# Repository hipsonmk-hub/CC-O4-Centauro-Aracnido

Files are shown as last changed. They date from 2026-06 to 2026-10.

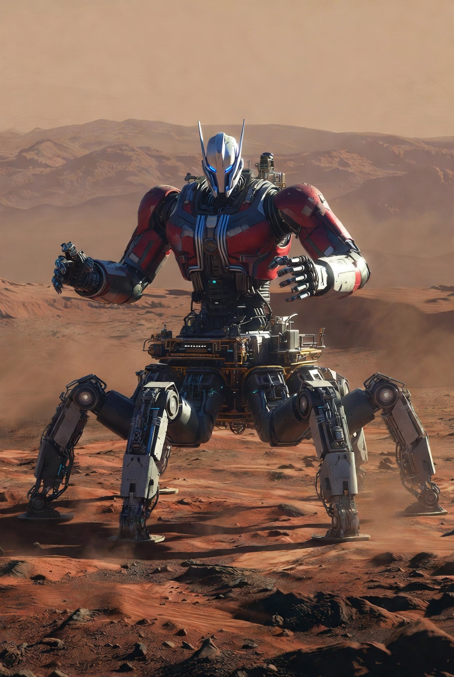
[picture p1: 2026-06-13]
image-1.jpg

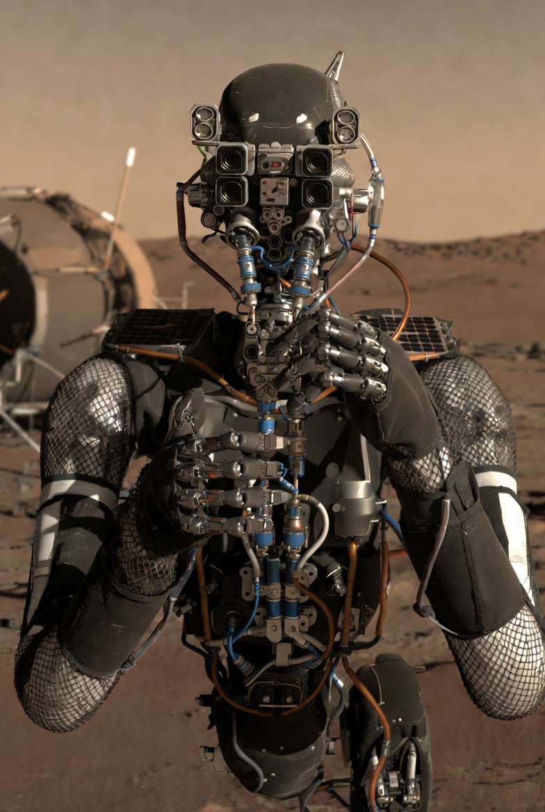
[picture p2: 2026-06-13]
image-3.jpg

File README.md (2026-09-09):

# CC-O4-Centauro-Aracnido
Arquitectura robótica híbrida Centauro-Arácnido para exploración lunar/marciana
# PROYECTO CC-04: ARQUITECTURA ROBÓTICA CENTAURO-ARÁCNIDO

**Solución Híbrida para Estabilidad y Operaciones Autónomas en Superficies Extraplanetarias**

**Código de Clasificación:** CC-O4-2026  
**Ecosistema Objetivo:** Exploración Lunar y Marciana (Compatibilidad Starship)  
**Fecha de Emisión:** Junio de 2026  
**Desarrollador de Arquitectura:** David Dorado Blázquez Moraleda López

## 1. Resumen Ejecutivo

El presente documento define la arquitectura conceptual de la plataforma robótica híbrida **CC-O4 (Centauro-Arácnido)**, diseñada para superar las limitaciones de rovers de ruedas y bípedos en entornos de microgravedad y terreno irregular.

Integra:
- Base octópoda hiper-redundante para anclaje extremo
- Torso antropomórfico modular (compatible con Optimus)
- Ecosistema energético piezoeléctrico
- Refrigeración vascular por nanotubos
- Núcleo cognitivo Edge AI con protocolo de "Ancla Lógica"

## 2. Morfología Modular y Compatibilidad "Plug & Play"

- **Base Octópoda de Anclaje Dinámico**: Ocho extremidades simétricas radiales. Centro de gravedad ultra-bajo y tolerancia a fallos (redistribución automática de carga).
- **Torso Humanoide Superior (Modularidad Optimus)**: Plataforma desmontable que permite acoplar directamente un torso humanoide estándar, combinando movilidad todoterreno con destreza fina.

## 3. Subsistemas Termodinámicos y Materiales Avanzados

- **Sistema Vascular Termodinámico**: Refrigeración activa mediante bomba central y líquido iónico/galinstano circulando por capilares de nanotubos de carbono.
- **Blindaje**: Ópticas con Gorilla Glass aeroespacial y protección con mallas multicapa de Kevlar balístico.

## 4. Arquitectura Energética Descentralizada

- **Cosecha Piezoeléctrica Dinámica**: Transductores PVDF en articulaciones y almohadillas que convierten tensión mecánica en electricidad.
- **Carga Inalámbrica por Inducción**: Evita puertos físicos que se obstruirían con regolito.

## 5. Arquitectura Cognitiva de Borde (Edge AI)

- **Procesamiento Multimodal (Gemma 4)**: Coordinación perfecta entre las 8 patas y las manos.
- **Protocolo "Ancla Lógica" (🔱)**: En caso de sobrecarga de datos, suspende tareas secundarias y prioriza homeostasis térmica y fijación al terreno.

## 6. Roadmap y Protocolo de Pruebas Terrestres

- **Fase 1**: Simulación en análogo terrestre (Nodo Móstoles) – tracción asimétrica y cosecha piezoeléctrica.
- **Fase 2**: Simulación de sobrecarga cognitiva (estilo Tesla Dojo).
- **Fase 3**: Pruebas en cámara de vacío y despliegue lunar.

## 7. Matriz de Rendimiento Extraplanetario

| Morfología de Plataforma | Estabilidad Cinética | Motricidad Fina | Tolerancia a Fallos | Autosuficiencia | Adaptabilidad a Marte |
|---|---|---|---|---|---|
| Rover de Ruedas Estándar | Media | Nula/Limitada | Baja | Baja | Media |
| Bípedo Humanoide Puro | Baja (microgravedad) | Alta | Muy Baja | Media | Baja |
| **Centauro-Arácnido (CC-O4)** | **Excelente** | **Alta** | **Extrema** | **Alta** | **Alta** |

---

**Imágenes y visuales del concepto** (incluye las que adjuntaste):
- Robot centauro-arácnido en superficie marciana
- Instalación de paneles solares
- Detalles mecánicos y close-ups
- 
Copyright (c) 2026 David Dorado Blázquez Moraleda López (@Hipsonmk)

This source describes Open Hardware and is licensed under the CERN-OHL-S v2.

You may redistribute and modify this source and make products using it under the terms of the CERN-OHL-S v2 (https://ohwr.org/cern_ohl_s_v2.txt).
This source is distributed WITHOUT ANY EXPRESS OR IMPLIED WARRANTY, INCLUDING OF MERCHANTABILITY, SATISFACTORY QUALITY AND FITNESS FOR A PARTICULAR PURPOSE. Please see the CERN-OHL-S v2 for applicable conditions.

Source location: https://github.com/hipsonmk-hub/CC-O4-Centauro-Aracnido

As per CERN-OHL-S v2 section 4, should you produce hardware based on this source, you must maintain the Creator's attribution and provide access to the modifications under the same license.
## ⚙️ Arquitectura Paramétrica y Hardware Abierto

El núcleo mecánico de la plataforma CC-O4 está diseñado bajo un paradigma paramétrico en **OpenSCAD**, garantizando su replicabilidad y adaptabilidad para misiones terrestres (NEXUS SHELL) y aeroespaciales.

### Nodo de Articulación Principal (`cc_o4_joint_624zz.scad`)
El primer módulo liberado establece el estándar de tolerancia termomecánica para las extremidades del octópodo. 

*   **Material Especificado:** PETG-CF (Fibra de carbono). Impresión orientada en el eje Z local (eje de bisagra) para evitar delaminación bajo carga.
*   **Hardware COTS:** Utiliza rodamientos 624ZZ (4x13x5) ajustados a presión (tolerancia `bearing_od_fit = 0.20`).
*   **Diseño Antidesgaste:** Implementa un eje de vástago liso de 4mm, evitando la fricción de hilos de rosca contra la pista interior del rodamiento.
*   **Retención Mecánica:** Sistema de tuerca cautiva DIN 934 insertada bajo el cajeado del rodamiento superior, garantizando integridad frente a vibraciones extremas o ciclos térmicos.

## ⚖️ Autoría y Licencia

Este proyecto es Hardware Abierto. Toda la arquitectura, diseño conceptual (CC-O4 y variantes NEXUS), lógica de control termodinámico (Galinstano) y scripts paramétricos son propiedad intelectual de **David Dorado Blázquez Moraleda López (@Hipsonmk)**. 

Distribuido bajo la licencia fuertemente recíproca **CERN-OHL-S v2**. Cualquier bifurcación, uso comercial, desarrollo estatal o derivación técnica debe hacer pública su arquitectura modificada y atribuir la autoría original de forma visible.

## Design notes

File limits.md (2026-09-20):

# limits.md — Nodo Móstoles / Fase 0

Valores que rompen piezas. No son marketing.

## Polímero
- PETG-CF en cajeado de 624ZZ: **tope operativo 65 °C**.
- Por encima: parar. El módulo cae y el rodamiento ovaliza el asiento.

## Tornillería
- M4 en rosca FDM: **1,2 – 1,5 N·m**. Rotura típica ~2,0 N·m.
- Junta de cintura CC-O4-W0 (aluminio 6082-T6): **M8 a 24 – 26 N·m**.
- No usar el par de la brida en una pata impresa.

## Watchdog (Ancla)
- WD_KICK periodo máximo **50 ms**.
- Latch a **100 ms** sin kick: ENABLE de drivers a bajo, TORSO_HOLD alto.
- Rearme solo con llave en la base. El SoC de aplicación no se rearma solo.

## Rodamiento / eje
- 624ZZ (4 × 13 × 5) sobre eje 4 mm.
- `bearing_od_fit` FDM: **0,20 mm** (ya en el repo).
- Tuerca cautiva DIN 934 donde el SCAD lo pida.

## Cintura CC-O4-W0
- Ø220 / PCD 190 / 8×M8 / pasadores Ø8 PCD 150 / arnés Ø70.
- Masa de diseño sobre la junta: **80 kg**.
- Ver `docs/CC-O4-W0_ICD_Cintura.pdf`.

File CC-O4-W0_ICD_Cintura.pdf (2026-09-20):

CC-O4-W0 · ICD DE CINTURA | PROPUESTA · ANÁLOGO TERRESTRE
CC-O4-2026 · Rev A · 2026-09-20 · No controlado por Tesla/SpaceX/xAI | pág. 1

## DOCUMENTO DE CONTROL DE INTERFAZ

# CC-O4-W0 — Cintura base octópoda / torso modular

Plataforma CC-O4 (Centauro-Arácnido) · Código CC-O4-2026 · Rev A · 20 septiembre 2026

Estado: PROPUESTA DE ANÁLOGO TERRESTRE (Nodo Móstoles, 1 g). No es el ICD de Tesla Optimus ni un contrato SpaceX. El patrón de taladros de cintura de Optimus no es público; esta brida define nuestro lado y un adaptador intermedio si algún día existe un torso real.

Campo | Valor
Identificador de interfaz | CC-O4-W0
Lado A (base) | Chasis octópodo CC-O4, plano de junta superior
Lado B (torso) | Torso humanoide o masa dummy 45 kg + payload 20 kg
Medio ambiente Fase 0 | Taller / exterior 1 g · −10 °C a +45 °C ambiente
Medio ambiente objetivo | Marte −90 °C a +20 °C · polvo · 0,38 g — NO cubierto por Rev A
Documentos padre | Proyecto CC-O4 jun-2026 · límites taller PETG-CF / watchdog

# 1. Alcance y no-alcance

Este ICD congela la unión mecánica, eléctrica, de datos y de seguridad entre la base de ocho patas y lo que se atornille encima. Congela también la secuencia de mate y el criterio de aceptación de Fase 0. No congela cinemática de patas, gait, visión, ni refrigeración vascular.
Fuera de alcance Rev A: galinstano, nanotubos, cosecha piezoeléctrica como fuente primaria, Gemma como lazo de servo, patrón oficial Tesla, calificación espacial.

# 2. Sistema de referencia

Origen {W} en el centro del plano de junta, cara de la base. +Z sale hacia el torso. +X proa (dirección de marcha nominal). +Y estribor. Regla de la derecha. El pasador maestro P1 está sobre +X a PCD 150 mm y define el clocking a 0°.
Tolerancia de clocking al mate: ±0,25°. Desalineación permitida en X/Y antes de entrar los pasadores: ±1,5 mm (los Ø8 h7/H7 corrigen el resto).

# 3. Interfaz mecánica

+X proa

+Y estribor

+Z hacia torso (sale del papel)

- Ø220 brida
- PCD 190 — 8×M8
- PCD 150 — 2×Ø8 h7
- Paso arnés Ø70
- Keep-out cables Ø100

Vista desde la base, plano de junta.

Unidades mm. No es ICD Tesla.

CC-O4-2026 · Rev A · 2026-09-20 · No controlado por Tesla/SpaceX/xAI | pág. 2
Cota / ítem | Valor | Nota
Diámetro exterior brida | Ø220 ±0,2 mm | Aluminio 6082-T6, e = 12 mm Fase 0
Plano de junta | Ra 1,6 · planeidad 0,05 mm | Sin pintura en corona de 12 mm
Paso de arnés | Ø70 +0,3/0 | Buje de desgaste nylon o PTFE
Keep-out cableado | Ø100 × 40 mm bajo y sobre junta | Nada de tornillos en este cilindro
Círculo de tornillos | PCD 190 ±0,1 · 8 × M8×1,25-6H | Ángulo 22,5° + n·45°
Tornillería | M8×30 12.9 + arandela Nord-Lock | Par 24–26 N·m, no usar M4 FDM aquí
Pasadores | 2 × Ø8 h7, PCD 150, a 0° y 180° | P1 maestro en +X · L útil 10 mm
Masa máx. sobre {W} | 80 kg (diseño) | 45 kg torso est. + 20 kg payload + margen
CG torso sobre junta | Z ≤ 450 mm · rXY ≤ 80 mm estático | Brazos extendidos: ver cargas

3.1 Cargas de diseño (límite). Factor último 1,5.

Caso | Fx, Fy | Fz (Z+ comp.) | Mx, My | Mz
Estático 1 g | 0 | 785 N | 80 N·m | 20 N·m
Marcha 1 g + frenada | 400 N | 1 100 N | 120 N·m | 40 N·m
Pata muerta / 3 puntos | 500 N | 1 200 N | 180 N·m | 60 N·m
Choque transporte 3 g | 800 N | 2 400 N | 250 N·m | 80 N·m
Brazo a 20 kg @ 0,6 m | 200 N | 1 000 N | 200 N·m | 50 N·m

La brida de Fase 0 en 6082-T6 e=12 con 8×M8 aguanta estos límites con margen si el par es el de la tabla. El cajeado FDM / 624ZZ / M4 a 1,2–1,5 N·m no vive en esta junta; vive en las patas. Mezclar los dos pares es cómo se cizalla una rosca impresa.

# 4. Interfaz eléctrica

Bus primario alineado a la cifra pública de paquete Optimus (~52 V). La base entrega; el torso consume. Retorno de potencia aislado del chasis. El chasis lleva PE a tierra de taller en Fase 0.

Red | Rango | Continuo | Pico 2 s | Conector Fase 0
VBUS_52 | 44–58 VDC | 15 A / 800 W | 28 A / 1,5 kW | SB50 rojo, 2 AWG o 2×10 mm²
V_LOGIC | 23–28 VDC | 2 A | 4 A | XT60 amarillo
V_WD | 3,3 V | 50 mA | — | JST-XH 3p en caja IP65
PE / chasis | — | — | — | Perno M6 junto a brida, marca ■
Protecciones en lado base: fusible ANL 40 A en VBUS, TVS 60 V, precharge 10 Ω / 200 ms antes de cerrar el contactor. Sin precharge no se mate el SB50 en caliente.

# 5. Datos y reloj de seguridad

Señal | Físico | Protocolo | Uso
ECAT_IN / OUT | 2 × M12 X-code | EtherCAT 100 Mbps | Lazo de torso y estado
CAN_SAFE | M12 A-code 5p | CAN 2.0B 1 Mbps | E-stop, modo, heartbeat
ENABLE_BASE | Par trenzado 24 V | activo alto, fail-safe bajo | Drivers de patas
ESTOP_LOOP | Lazo seco NC | serie con seta de base y torso | Abre contactor VBUS
WD_KICK | 3,3 V pulso | periodo ≤ 50 ms | Watchdog independiente
TORSO_HOLD | 24 V | activo si Ancla | Torso congela brazos

## 5.1 Protocolo Ancla (watchdog) — contrato de tiempo

El watchdog vive en una placa aparte, no en el SoC que se puede colgar. El cerebro de borde debe emitir WD_KICK cada ≤ 50 ms. Si el periodo supera 100 ms, el latch abre ENABLE_BASE (patas a torque-off / freno si lo hay), afirma TORSO_HOLD y no rearma solo: hace falta ciclo de llave en la base. Eso corta el martillo gravitatorio. No se debate en software de aplicación.

CC-O4-2026 · Rev A · 2026-09-20 · No controlado por Tesla/SpaceX/xAI | pág. 3

# 6. Térmica y estanqueidad Fase 0

Ítem | Límite
Cajeados PETG-CF ajenos a esta brida | 65 °C metal del 624ZZ. Por encima, parar.
Brida 6082 en sol de taller | Medir; no hay recubrimiento espacial en Rev A
IP de conectores | IP65 mínimo en SB50 / M12 con tapa
Regolito / polvo Fase 0 | Fuelle de tela sobre el Ø70 si hay ensayo de arena

# 7. Secuencia de mate y desmate

1) Ambos lados sin tensión, ESTOP abierto, llave de base en OFF.
2) Alinear P1 con la marca +X. Bajar el torso a 5 mm. Entrar pasadores.
3) Ocho M8 a mano. Par 25 N·m en estrella (1-5-3-7-2-6-4-8).
4) Conectar primero PE, luego SB50, luego XT60, luego M12, luego WD.
5) Precharge. Cerrar contactor. Ver 52 V y heartbeat CAN < 1 s.
6) Armar ENABLE solo si WD_KICK está vivo 2 s seguidos.
Desmate: inverso. Nunca desenchufar SB50 en caliente.

# 8. Verificación Fase 0

ID | Ensayo | Criterio de paso
W0-M1 | Calibre PCD y pasadores | Pines entran sin mazo; holgura radial ≤ 0,03 mm
W0-M2 | Par M8 + marcas | 25 ±1 N·m, Nord-Lock sentada
W0-L1 | Dummy 57 kg + 20 kg en voladizo 0,4 m | Sin fluencia; planeidad post-carga ≤ 0,08 mm
W0-E1 | Aislamiento VBUS–chasis | ≥ 10 MΩ @ 250 VDC
W0-E2 | Precharge + contactor | Inrush < 40 A pico
W0-S1 | Quitar WD_KICK | ENABLE cae ≤ 100 ms; no rearme autónomo
W0-S2 | Abrir ESTOP en marcha lenta | VBUS abierto; patas torque-off
W0-T1 | Termopar en cajeado pata | Nunca > 65 °C en PETG-CF

# 9. Adaptador hacia un torso tipo Optimus

Si en el futuro existe un torso real, no se rediseña la base: se fabrica una arandela-adaptador de 12 mm con CC-O4-W0 abajo y el patrón que publique el fabricante arriba. Hasta entonces el lado B es un dummy de 45–57 kg con los mismos conectores. Quien afirme “plug & play Optimus” sin esa arandela miente.

# 10. Lista corta de compra Fase 0

Pieza | Qty | Notas
Placa 6082-T6 250×250×12 | 2 | Base + dummy. CNC o agua + taladro plantilla
Pasador Ø8 h7 × 20 | 2+2 | Repuesto
Tornillo M8×30 12.9 + Nord-Lock M8 | 8+8 | No zinc barato
Anderson SB50 + contactos | 2 pares | Rojo VBUS
XT60 + M12 A-code + M12 X-code | 1 juego | Con tapas
Contactor 48–60 V + precharge | 1 | Bobina 24 V
MCU watchdog (STM32/ATTINY aislado) | 1 | No compartir cristal con el cerebro

Fin Rev A. Siguiente documento natural: presupuesto de masa/potencia de la base octópoda (no de esta brida). Esta junta ya se puede dibujar en CAD mañana.

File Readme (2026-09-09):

### Embudo de Recarga R2F (Rapid Refill) y Válvula Dry-Break (`nexus_r2f_drybreak_funnel.scad`)
El núcleo logístico de las operaciones de superficie y de la variante terrestre NEXUS SHELL. Permite la transferencia de fluidos o agente bloqueador a alto caudal (45 L/min) en laderas irregulares sin necesidad de precisión milimétrica.

*   **Guía Cónica de Tolerancia Amplia:** El diseño del embudo compensa las desalineaciones físicas entre el brazo del robot logístico y la unidad de vanguardia durante operaciones en pendiente.
*   **Purga Neumática Pre-Contacto:** Incorpora un anillo perimetral con 8 inyectores (`purge_hole_dia = 2.5`) diseñados para disparar un soplado de aire a 8 bar milisegundos antes del acoplamiento físico.
*   **Operación Anti-Contaminación:** Este sistema expulsa ceniza incandescente o regolito lunar abrasivo del área de la junta tórica, garantizando un sellado hermético en condiciones de visibilidad cero sin contaminar los depósitos internos.

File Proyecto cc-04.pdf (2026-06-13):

PROYECTO CC-O4: ARQUITECTURA ROBÓTICA CENTAURO-ARÁCNIDO

Solución Híbrida para Estabilidad y Operaciones Autónomas en Superficies Extraplanetarias

Código de Clasificación: CC-O4-2026

Ecosistema Objetivo: Exploración Lunar y Marciana (Compatibilidad Starship)

Fecha de Emisión: Junio de 2026

Desarrollador de Arquitectura: David Dorado Blázquez Moraleda López

## 1. Resumen Ejecutivo

El presente documento técnico define la arquitectura conceptual de la plataforma robótica híbrida CC-O4 (Centauro-Arácnido), diseñada para superar de manera definitiva las vulnerabilidades de los rovers de ruedas y los bípedos puros en entornos de microgravedad y terreno irregular. El sistema integra una base octópoda hiper-redundante para anclaje extremo, combinada con un torso antropomórfico modular de motricidad fina. El diseño incluye un ecosistema energético piezoeléctrico, refrigeración vascular por nanotubos y un núcleo cognitivo de vanguardia (Edge AI) capaz de gestionar la sobreinformación táctica mediante protocolos de interrupción lógica.

## 2. Morfología Modular y Compatibilidad "Plug & Play"

La optimización cinemática exige disociar las funciones de tracción pesada y manipulación fina, maximizando el hardware ya existente en la industria.

- Base Octópoda de Anclaje Dinámico: Ocho extremidades articuladas de configuración simétrica radial. Proporcionan un centro de gravedad ultra-bajo y permiten el anclaje físico en pendientes extremas. Si una articulación falla por impactos micrometeoríticos o abrasión de regolito marciano, el algoritmo cinemático redistribuye la carga, manteniendo la operatividad total.
- Torso Humanoide Superior (Modularidad Optimus): La base arácnida está diseñada como una plataforma modular desmontable. Permite que el torso superior de plataformas humanoides estándar (como Tesla Optimus) se acople directamente al chasis inferior. Esto permite reutilizar el hardware de motricidad fina ya desarrollado, dotándolo instantáneamente de movilidad todoterreno sin riesgo de volcadura.

## 3. Subsistemas Termodinámicos y Materiales Avanzados

Para resistir los gradientes térmicos extremos (-60°C a 20°C en Marte) y la abrasión del polvo de silicio, el revestimiento utiliza materiales aeroespaciales:

- Sistema Vascular Termodinámico: El calor crítico generado por el procesamiento de la IA no se disipa con ventiladores (inútiles en el vacío o atmósferas tenues). Una bomba central hace circular "sangre refrigerante" (líquido iónico/galinstano) a través de capilares de nanotubos de carbono, extrayendo el calor residual de los motores y procesadores hacia paneles radiadores.
- Blindaje: Ópticas recubiertas con Gorilla Glass de grado aeroespacial y servomotores protegidos por mallas flexibles multicapa de Kevlar balístico.

## 4. Arquitectura Energética Descentralizada

El CC-O4 elimina la dependencia pasiva de fuentes externas, recolectando energía de su propia interacción física con el entorno.

- Cosecha Piezoeléctrica Dinámica: Las ocho articulaciones y almohadillas de contacto integran transductores piezoeléctricos (PVDF). La tensión mecánica del propio peso del robot al caminar y anclarse exprime electrones, convirtiendo el estrés cinético en carga eléctrica directa.
- Carga Inalámbrica por Inducción: Para recargas pesadas, el robot se posiciona sobre nodos de inducción magnética estacionarios, evitando puertos físicos que se bloquearían con el regolito.

## 5. Arquitectura Cognitiva de Borde (Edge AI)

La latencia de las comunicaciones Tierra-Marte (hasta 48 minutos) exige autonomía total en el nanosegundo.

- Procesamiento Multimodal (Gemma 4): El robot ejecuta redes neuronales directamente en su chasis. Procesa la telemetría óptica, térmica y piezoeléctrica como un vector unificado, permitiendo una coordinación perfecta entre las 8 patas y las manos de ensamblaje.
- Protocolo de "Ancla Lógica" (🔱): Desarrollado para evitar el colapso del sistema ante tormentas de datos. Si el procesador experimenta sobreinformación crítica, el protocolo suspende automáticamente tareas secundarias (mapeo, optimización) y "ancla" el 100% de los teraflops exclusivamente en la homeostasis térmica y la fijación al terreno, hasta purgar el exceso de datos.

## 6. Roadmap y Protocolo de Pruebas Terrestres

El despliegue táctico se estructura en tres fases de simulación antes del lanzamiento en Starship.

- Fase 1: Simulación de Análogo Terrestre (Parámetros Nodo Móstoles). Pruebas de tracción asimétrica y cosecha piezoeléctrica (Escala 1G). Utilizando cartografía técnica urbana y desniveles mapeados para testear la redistribución del centro de masa del torso modular.
- Fase 2: Simulación de Sobrecarga Cognitiva. Estrés de la red neuronal en simuladores virtuales (arquitectura tipo Tesla Dojo) para calibrar el tiempo de respuesta del protocolo "Ancla Lógica".
- Fase 3: Operación en Cámara de Vacío y Despliegue Lunar. Pruebas del sistema vascular de galinstano bajo radiación solar directa.

## 7. Matriz de Rendimiento Extraplanetario

Morfología
de
Plataforma

Estabilidad
Cinética

Motricidad
Fina

Tolerancia a
Fallos

Autosuficie
ncia

Adaptabilid
ad a Marte

Rover de
Ruedas
Estándar
Media | Nula /
Limitada
Baja | Baja | Media

Bípedo
Humanoide
Puro

Baja
(micrograved
ad)
Alta | Muy Baja | Media | Baja (Riesgo viento/polvo)

Centauro-Ar
ácnido
(CC-O4)

Excelente Alta (Torso
Modular)

Extrema Alta
(Piezoeléctri
ca)

Alta

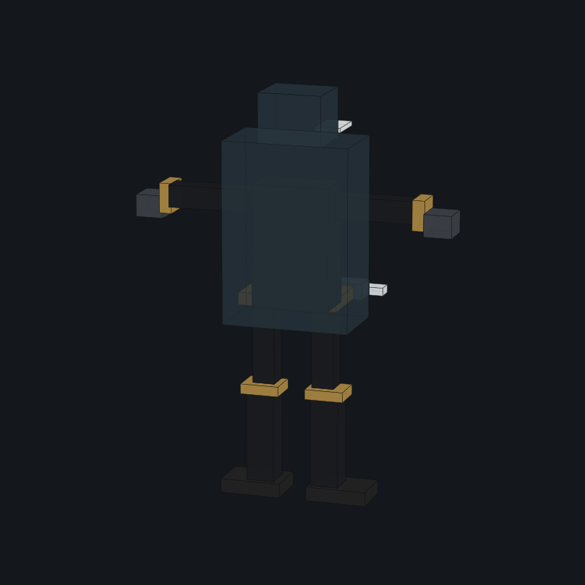
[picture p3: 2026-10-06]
grok_1791292865477.png

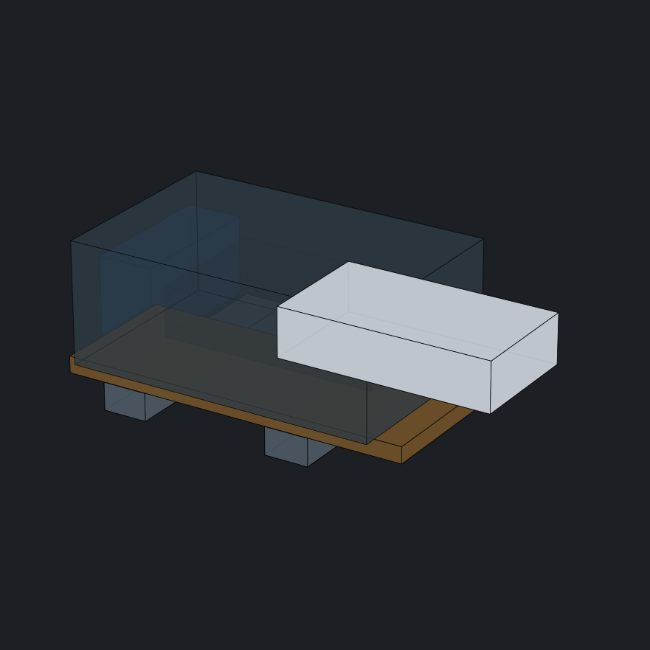
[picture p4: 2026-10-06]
grok_1791292685375.png

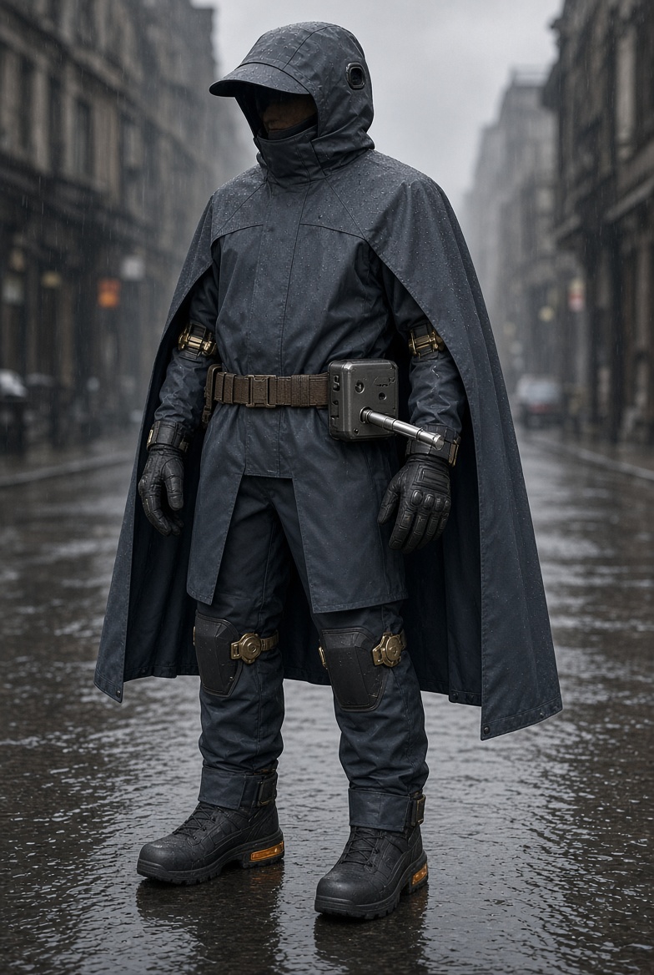
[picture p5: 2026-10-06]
grok_1791292872290.jpg

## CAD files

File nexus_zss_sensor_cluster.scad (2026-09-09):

// CC-O4 / NEXUS SHELL — ZSS (Zero Sight Suite) Sensor Cluster
// Licencia: CERN-OHL-S v2
// Desarrollador: David Dorado Blázquez Moraleda López (@Hipsonmk)
//
// Descripción: Chasis del módulo de percepción multimodal ZSS.
// Aloja LiDAR Multi-Eco SWIR, cámaras LWIR estéreo, radar FMCW,
// sensores ultrasónicos y hardware de navegación (IMU táctica + UWB).
// Diseñado con planos angulares para desviar calor radiante y escombros.

/* [Dimensiones del Cluster ZSS] */
zss_width = 140.0;
zss_height = 80.0;
zss_depth = 90.0;
wall_thickness = 4.0;

/* [Ventanas de Sensores] */
lidar_dia = 45.0;       // LiDAR SWIR central (visibilidad a través de humo/polvo)
lwir_dia = 22.0;        // Lentes estéreo LWIR (Infrarrojo Térmico)
lwir_baseline = 90.0;   // Separación estéreo (línea base para profundidad)
us_dia = 16.0;          // Transductores ultrasónicos
        
$fn = 80;

// --- Cuerpo Principal (Diseño Angular/Faceted) ---
module zss_shell() {
    difference() {
        // Bloque exterior trapezoidal (desvío aerodinámico y balístico)
        hull() {
            translate([0, zss_depth/2 - 10, -zss_height/2 + 10]) 
                cube([zss_width, 20, 20], center=true); // Frente bajo
            translate([0, zss_depth/2 - 10, zss_height/2 - 10]) 
                cube([zss_width - 30, 20, 20], center=true); // Frente alto (inclinado)
            translate([0, -zss_depth/2 + 10, 0]) 
                cube([zss_width - 20, 20, zss_height], center=true); // Trasera
        }

        // Vaciado interno para la electrónica Edge AI y cableado
        hull() {
            translate([0, zss_depth/2 - 10, -zss_height/2 + 10]) 
                cube([zss_width - wall_thickness*2, 20, 20 - wall_thickness], center=true);
            translate([0, zss_depth/2 - 10, zss_height/2 - 10]) 
                cube([zss_width - 30 - wall_thickness*2, 20, 20 - wall_thickness], center=true);
            translate([0, -zss_depth/2 + 10, 0]) 
                cube([zss_width - 20 - wall_thickness*2, 20, zss_height - wall_thickness*2], center=true);
        }

        // 1. Apertura Central: LiDAR SWIR 1.5 µm
        translate([0, zss_depth/2, 0])
            rotate([90, 0, 0])
            cylinder(d=lidar_dia, h=30, center=true);

        // 2. Aperturas Estéreo: Cámaras LWIR (Infrarrojo Térmico)
        translate([lwir_baseline/2, zss_depth/2, 0])
            rotate([90, 0, 0])
            cylinder(d=lwir_dia, h=30, center=true);
        translate([-lwir_baseline/2, zss_depth/2, 0])
            rotate([90, 0, 0])
            cylinder(d=lwir_dia, h=30, center=true);

        // 3. Sensores Ultrasónicos (Inclinados hacia el suelo para mapeo cercano)
        translate([lwir_baseline/2 - 15, zss_depth/2 - 12, -zss_height/2 + 5])
            rotate([90, 20, 0])
            cylinder(d=us_dia, h=30, center=true);
        translate([-lwir_baseline/2 + 15, zss_depth/2 - 12, -zss_height/2 + 5])
            rotate([90, -20, 0])
            cylinder(d=us_dia, h=30, center=true);
            
        // 4. Panel de interfaz de montaje (Cuello)
        translate([0, -zss_depth/4, -zss_height/2])
            cylinder(d=40, h=15, center=true);
    }
}

// --- Paneles Radar FMCW ---
module radar_panels() {
    // Los radares de onda continua (77-81 GHz) van sellados tras los laterales angulados
    // para protección total frente a ceniza o polvo.
    color("DarkSlateGray") {
        translate([zss_width/2 - 12, 0, 0])
            rotate([0, 15, 0])
            cube([4, 40, 40], center=true);
        translate([-zss_width/2 + 12, 0, 0])
            rotate([0, -15, 0])
            cube([4, 40, 40], center=true);
    }
}

// --- Base de Acoplamiento y Rutas de Datos ---
module mounting_interface() {
    // Interfaz base para anclar al torso, con canal para bus UWB y alimentación
    translate([0, -zss_depth/4, -zss_height/2 - 5])
    difference() {
        cylinder(d=45, h=10, center=true);
        cylinder(d=25, h=12, center=true); // Canal interno de cables
        
        // Agujeros de anclaje (M4)
        for (i = [0:90:270]) {
            rotate([0, 0, i])
            translate([16, 0, 0])
            cylinder(d=4.5, h=12, center=true);
        }
    }
}

// Ensamblaje Final
union() {
    color([0.20, 0.22, 0.25]) zss_shell();
    radar_panels();
    color([0.45, 0.45, 0.48]) mounting_interface();
}
### Módulo de Percepción ZSS - Zero Sight Suite (`nexus_zss_sensor_cluster.scad`)
El chasis cognitivo de la plataforma. Diseñado con una morfología angular/trapezoidal, su función es alojar el clúster de sensores evitando la acumulación de ceniza, regolito y desviando el calor radiante. 

*   **Fusión Multimodal:** Incorpora espacios paramétricos para un LiDAR Multi-Eco SWIR (1.5 µm) central, y cámaras estéreo LWIR (8-14 µm) con una línea base de 90mm (`lwir_baseline = 90.0`) para calcular profundidad en visibilidad cero.
*   **Paneles FMCW Integrados:** Laterales angulados diseñados para alojar radares FMCW de 77–81 GHz operando a través de la carcasa sellada.
*   **Mapeo de Proximidad:** Puertos inferiores inclinados 20 grados para transductores ultrasónicos, permitiendo topografía del suelo y detección de obstáculos inmediatos.

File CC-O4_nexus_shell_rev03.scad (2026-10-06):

// =====================================================================
// CC-O4 NEXUS SHELL - DOMINIO 1: MÓDULO TÁCTICO ZINC-AIRE (REV 0.3)
// Arquitectura: circuito abierto al ambiente, cerrado al traje y a la lluvia
// Filosofía: el ánodo es combustible sólido; el oxígeno no es el de respirar
// =====================================================================
//
// Cambios frente a REV 0.2
// - El cinturón no atraviesa la cámara húmeda. Va por dos puentes externos.
// - El cátodo no mira al cielo. Toma aire lateral, con labio y membrana.
// - El cartucho es cassette completo (ánodo + gel + separador), no un lingote.
// - Contactos al fondo del riel, chaveta de polaridad, pestillo de retención.
// - Bahía seca separada para el elevador. El KOH no llega a la electrónica.
// - Química única: zinc-aire. El aluminio-aire suelta hidrógeno; no comparte venteo.
// - Persianas de cátodo cerrables: en modo traje sellado el módulo se aísla.

cinturon_ancho = 50;
cinturon_grosor = 8;
grosor_pared = 3.5;

modulo_largo = 112;
modulo_ancho = 72;
modulo_alto = 44;

cartucho_largo = 78;
cartucho_ancho = 48;
cartucho_alto = 18;

bahia_seca_largo = 22;
$fn = 48;

module chasis_principal() {
    difference() {
        hull() {
            for (x = [-1, 1])
                for (y = [-1, 1])
                    for (z = [-1, 1])
                        translate([x * (modulo_largo/2 - 3), y * (modulo_ancho/2 - 3), z * (modulo_alto/2 - 3)])
                            sphere(r = 3);
        }

        // Cámara húmeda: cassette por la cara frontal (+X)
        translate([6, 0, 2])
            cube([cartucho_largo + 0.6, cartucho_ancho + 0.5, cartucho_alto + 0.45], center = true);

        // Chaveta de polaridad: impide girar el cassette
        translate([cartucho_largo/2 - 8, cartucho_ancho/2 - 6, 2])
            cube([10, 6, cartucho_alto + 1], center = true);

        // Bahía seca trasera, sin comunicación con la cámara húmeda
        translate([-modulo_largo/2 + bahia_seca_largo/2 + grosor_pared, 0, 1])
            cube([bahia_seca_largo - 1, modulo_ancho - 16, modulo_alto - 14], center = true);

        // Tomas laterales del cátodo. No en la tapa superior.
        for (i = [-18 : 12 : 18]) {
            translate([i + 4, modulo_ancho/2, 4])
                rotate([90, 0, 0])
                cylinder(d = 3.2, h = 12, center = true);
            translate([i + 4, -modulo_ancho/2, 4])
                rotate([90, 0, 0])
                cylinder(d = 3.2, h = 12, center = true);
        }

        // Drenaje de condensado, no venteo de gas de ánodo
        translate([8, 0, -modulo_alto/2])
            cylinder(d = 2.4, h = 8, center = true);
    }
}

module puente_cinturon() {
    difference() {
        cube([16, cinturon_ancho + 8, cinturon_grosor + 6], center = true);
        cube([16 + 2, cinturon_ancho, cinturon_grosor], center = true);
    }
}

module cartucho_zinc() {
    difference() {
        cube([cartucho_largo, cartucho_ancho, cartucho_alto], center = true);
        // Muesca de pestillo
        translate([-cartucho_largo/2 + 4, 0, cartucho_alto/2])
            cube([8, 14, 4], center = true);
        // Chaflán de la chaveta
        translate([0, cartucho_ancho/2, 0])
            cube([cartucho_largo + 2, 5, cartucho_alto + 2], center = true);
    }
}

color("DarkSlateGray") chasis_principal();

for (x = [-34, 34])
    translate([x, 0, -modulo_alto/2 - 4])
        color("DimGray") puente_cinturon();

translate([46, 0, 2])
    color("Silver") cartucho_zinc();

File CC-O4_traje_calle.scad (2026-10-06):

// =====================================================================
// CC-O4 NEXUS SHELL — TRAJE DE CALLE (REV 0.1)
// Un solo archivo. Unidades: milímetros.
//
// Qué es este traje
//   Capa de lluvia de perfil bajo, no paraguas.
//   Apoyo solo donde hay camino de carga y ciclo: talón, rodilla, codo, nudillo.
//   El roce difuso del torso no cosecha.
//   Zinc-aire en el cinturón, circuito abierto al ambiente, cerrado al aire de respirar.
//   Modo calle: no sellado. El modo galería no vive en este archivo.
//
// Piezas
//   01 capa y capucha con visera
//   02 guantes de nudillo (verano = bisagra textil; invierno = mismo guante + tendón)
//   03 suela de carrera corta
//   04 cinturón, módulo zinc-aire REV 0.3, bahía seca
//   05 bisagras de codo y rodilla
// =====================================================================

$fn = 24;

altura_usuario = 1760;
escala = altura_usuario / 1760;

// --- materiales (solo color de vista) ---
col_capa   = [0.16, 0.20, 0.22];
col_base   = [0.10, 0.11, 0.13];
col_guante = [0.22, 0.24, 0.26];
col_suela  = [0.12, 0.12, 0.12];
col_zinc   = [0.75, 0.77, 0.80];
col_seco   = [0.15, 0.28, 0.42];
col_cint   = [0.28, 0.20, 0.12];
col_bis    = [0.45, 0.38, 0.16];

module elipse(rx, ry, h) {
    scale([rx, ry, 1]) cylinder(r = 1, h = h, center = true);
}

// ---------------------------------------------------------------------
// 01  CAPA
//     Caída por delante de la rodilla. Bajo libre. Visera corta.
//     Abertura trasera de capucha para que la ráfaga no infle.
// ---------------------------------------------------------------------
module capa() {
    color(col_capa) {
        difference() {
            union() {
                // cuerpo de capa, más larga delante
                hull() {
                    translate([0, 0, 1280]) elipse(210, 150, 20);
                    translate([10, 40, 760]) elipse(250, 180, 16);
                    translate([-20, -30, 760]) elipse(230, 170, 16);
                }
                // hombrera que escurre
                translate([0, 0, 1360]) elipse(240, 160, 30);
                // capucha
                translate([-20, 0, 1520]) sphere(r = 130);
                // visera rígida corta
                translate([95, 0, 1505]) rotate([0, 70, 0]) cube([70, 150, 6], center = true);
            }
            // hueco interior
            translate([0, 0, 1100]) cube([340, 260, 900], center = true);
            // boca de cara
            translate([90, 0, 1520]) cube([80, 110, 90], center = true);
            // abertura trasera de presión
            translate([-140, 0, 1540]) cube([40, 36, 28], center = true);
            // bajo abierto: no es un saco
            translate([0, 0, 700]) cube([520, 400, 80], center = true);
        }
        // dobladillo con lastre (el viento levanta y sale, no hace campana)
        translate([20, 50, 790]) color([0.30, 0.32, 0.28]) elipse(240, 12, 8);
    }
}

module base_torso() {
    color(col_base) {
        translate([0, 0, 1180]) elipse(160, 110, 340);
        translate([0, 0, 1000]) elipse(150, 105, 80);
    }
}

// ---------------------------------------------------------------------
// 05  EXTREMIDAD CON BISAGRA
//     La bisagra es el generador. La manga lisa no.
// ---------------------------------------------------------------------
module segmento(l, r) {
    cylinder(r = r, h = l);
    translate([0, 0, l]) sphere(r = r);
}

module bisagra() {
    color(col_bis) rotate([90, 0, 0]) cylinder(r = 14, h = 28, center = true);
}

module brazo() {
    color(col_base) segmento(240, 38);
    translate([0, 0, 250]) bisagra();
    translate([0, 0, 260]) color(col_base) segmento(220, 32);
}

module pierna() {
    color(col_base) segmento(380, 55);
    translate([0, 0, 390]) bisagra();
    translate([0, 0, 400]) color(col_base) segmento(360, 42);
}

// ---------------------------------------------------------------------
// 02  GUANTE
//     Verano: bisagra de nudillo, dorso activo, palma libre de sudor.
//     Invierno: la misma bisagra más tendón dorsal. Mismo archivo.
// ---------------------------------------------------------------------
module dedo(l, r) {
    color(col_guante) {
        cylinder(r = r, h = l * 0.45);
        translate([0, 0, l * 0.45]) color(col_bis) sphere(r = r + 1.5); // nudillo activo
        translate([0, 0, l * 0.50]) cylinder(r = r * 0.85, h = l * 0.5);
    }
}

module guante(invierno = false) {
    color(col_guante) {
        translate([0, 0, 0]) scale([1, 0.7, 0.55]) sphere(r = 42);
        if (invierno)
            translate([-8, 0, 6]) cube([36, 8, 6], center = true); // tendón dorsal
    }
    for (a = [-30, -10, 10, 30])
        rotate([0, 0, a]) translate([0, 28, 8]) rotate([70, 0, 0]) dedo(52, 7);
    rotate([0, 20, 40]) translate([0, 18, -6]) dedo(40, 8); // pulgar
}

// ---------------------------------------------------------------------
// 03  SUELA DE CARRERA CORTA
//     4 mm de carrera útil. Tope rígido al fondo. Energía por paso ~ F·δ.
// ---------------------------------------------------------------------
module bota() {
    color(col_suela) {
        hull() {
            translate([-20, 0, 16]) cube([150, 90, 16], center = true);
            translate([70, 0, 20]) cube([80, 70, 12], center = true);
        }
        // tope de carrera
        translate([-55, 0, 6]) cube([40, 50, 6], center = true);
        // celda de talón, cámara de 4 mm
        color([0.35, 0.32, 0.20]) translate([-55, 0, 14]) cube([36, 44, 4], center = true);
    }
}

// ---------------------------------------------------------------------
// 04  CINTURÓN Y MÓDULO ZINC-AIRE
//     Bahía húmeda delante-lateral. Bahía seca al otro lado de la pared.
//     El cinturón no atraviesa el vaso.
// ---------------------------------------------------------------------
module modulo_zinc() {
    color([0.18, 0.22, 0.26]) difference() {
        cube([112, 72, 44], center = true);
        translate([16, 0, 2]) cube([78, 48, 18], center = true);
        translate([-40, 0, 0]) cube([20, 52, 28], center = true);
    }
    // cassette a medio extraer, solo en vista explosionada
    color(col_zinc) translate([70, 0, 2]) cube([78, 46, 16], center = true);
    color(col_seco) translate([-40, 0, 0]) cube([16, 40, 22], center = true);
}

module cinturon() {
    color(col_cint) difference() {
        elipse(175, 125, 18);
        elipse(155, 108, 22);
    }
    // puentes, no túnel a través de la cámara
    for (x = [-20, 28])
        translate([x, 150, -8]) color([0.25, 0.27, 0.30]) cube([16, 16, 14], center = true);
    translate([8, 168, 10]) modulo_zinc();
    // nodo / condensador del traje, bahía seca de sistema
    translate([-150, 40, 8]) color(col_seco) cube([36, 22, 14], center = true);
}

// ---------------------------------------------------------------------
// ENSAMBLAJE — modo calle, de pie, brazos separados para ver el guante
// invierno = true añade el tendón dorsal. No cambia el casco ni la suela.
// ---------------------------------------------------------------------
invierno = true;
explosion = false; // true separa el cassette; el módulo ya lo muestra extraído

translate([0, 0, 0]) base_torso();
translate([0, 0, 0]) capa();

translate([-210, 0, 1320]) rotate([0, 18, 180]) brazo();
translate([210, 0, 1320]) rotate([0, -18, 0]) brazo();

translate([-250, 20, 860]) rotate([0, 70, 0]) guante(invierno);
translate([250, 20, 860]) rotate([0, -70, 180]) guante(invierno);

translate([-90, 0, 200]) pierna();
translate([90, 0, 200]) pierna();

translate([-90, 10, 16]) bota();
translate([90, 10, 16]) rotate([0, 0, 0]) bota();

translate([0, 0, 980]) cinturon();

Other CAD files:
CC04_F0_piezo_capsule.scad
Rev2.scad
cc_o4_hybrid_anchor_foot.scad
cc_o4_w0_flange.scad
nexus_r2f_drybreak_funnel.scad
profiles/env_profiles.scad
skunx_al_air_02.scad

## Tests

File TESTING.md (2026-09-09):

// NEXUS-L Arm Kinematic Routine: Hot-Swap for SKUNX-AL-AIR-02
// Bay Constraints: 120x90 mm cross-section, Length: 448 mm[span_0](start_span)[span_0](end_span)

#include <NexusArmRTOS.h>
#include <SKUNX_AlAir.h>

void executeHotSwapSequence() {
    ArmController.setEndEffector(TOOL_QUICK_RELEASE_GRIPPER);
    
    // 1. Aproximación lineal al chasis hexápodo (Bahía 120x90 mm)[span_1](start_span)[span_1](end_span)
    Arm.moveToCoordinates(BAY_AL_AIR_POS, APPROACH_VECTOR_Z, 50.0); // mm/s
    
    // 2. Desacople de los puertos mecánicos y roscas M20 de transferencia[span_2](start_span)[span_2](end_span)
    Arm.actuateValves(M20_PORT_LOCK, UNLOCK);
    
    // 3. Sujeción del tirador táctico quick-release (80x30 mm)[span_3](start_span)[span_3](end_span)
    Arm.closeGripper(HANDLE_80X30_MM);
    
    // 4. Extracción lineal del cartucho agotado a lo largo del eje de 448 mm[span_4](start_span)[span_4](end_span)
    Arm.linearRetract(448.0, 20.0); // mm
    
    // 5. Ciclo de intercambio: Desechar unidad oxidada y posicionar nueva celda Al-Air (5.0 kg)[span_5](start_span)[span_5](end_span)
    Arm.swapCartridgeBay(SLOT_FRESH_UNIT);
}

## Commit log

2026-09-09 Add CC-O4 docking ring design in OpenSCAD
    This file defines a mechanical docking ring for a humanoid torso, including parameters for dimensions, tolerances, and assembly modules.
    [cc_o4_torso_docking_ring.scad]
2026-09-09 Add conical coupling interface for fluid operations
    This file defines a conical coupling interface for fluid operations, including a dry-break valve and pneumatic purge system, designed for uninterrupted operation on slopes.
    [nexus_r2f_drybreak_funnel.scad]
2026-09-09 Create ZSS sensor cluster design in OpenSCAD
    Added the ZSS sensor cluster design with multiple sensor accommodations and structural details.
    [nexus_zss_sensor_cluster.scad]
2026-09-09 Implement CC-O4 hybrid anchor foot module
    Added a new module for the CC-O4 hybrid anchor foot designed for microgravity applications. This includes pneumatic anchoring, cryogenic locking, and piezoelectric harvesting systems.
    [cc_o4_hybrid_anchor_foot.scad]
2026-09-09 Add logical anchor protocol for system stability
    Implement hardware interrupt for cognitive load monitoring and stabilization protocol.
2026-09-09 Add skunx_al_air_02.scad with parametric design
    [skunx_al_air_02.scad]
2026-09-09 Implement hot-swap FSM for Nexus ARM RTOS
2026-09-09 Add physical parameters and hot-swap FSM logic
    [skunx_al_air_02.scad]
2026-09-27 Add piezo capsule design in OpenSCAD
    Initial commit of the piezo capsule design in OpenSCAD.
    [CC04_F0_piezo_capsule.scad]
2026-09-27 Add Rev2.scad for piezoelectric shoe design
    [Rev2.scad]
2026-09-29 Add environmental profiles for operational modes
    This file defines environmental profiles for different operational modes, including material properties, tolerances, and rendering colors based on the selected mode.
    [env_profiles.scad]
